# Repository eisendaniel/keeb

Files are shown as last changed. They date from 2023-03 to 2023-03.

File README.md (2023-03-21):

# un**ORTHO**dox

Devices

* UNO-XXX are main hosts, direct USB HID devices
* DOX-XXX are I2C expansion modules, connected via TRRS to the I2C bus and 5V power rails

## **UNO-W14** : 14x5 ortholinear keyboard

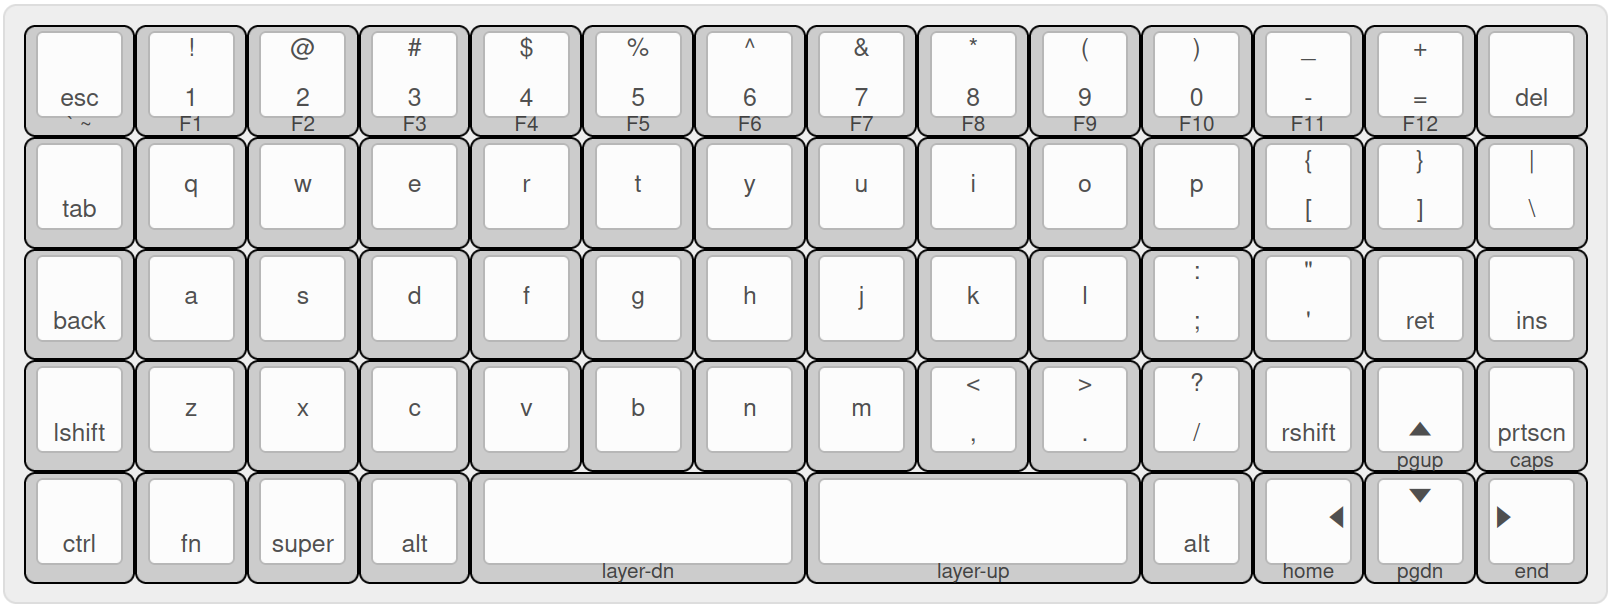
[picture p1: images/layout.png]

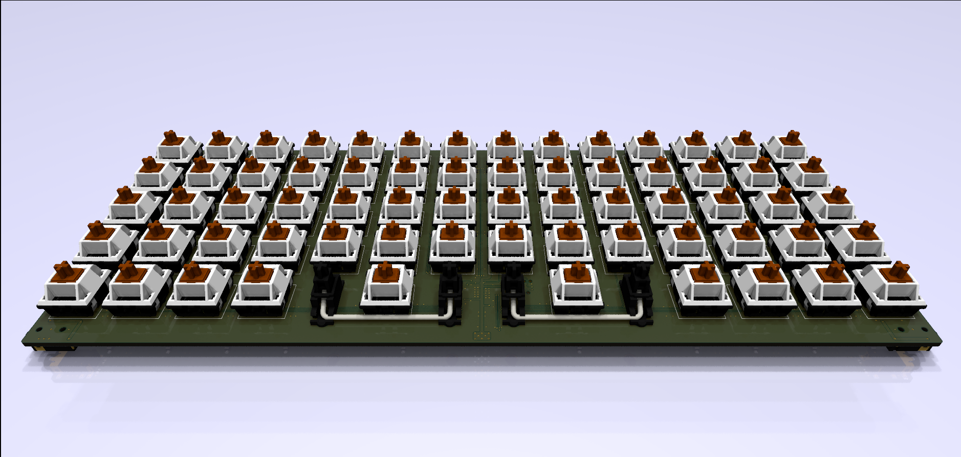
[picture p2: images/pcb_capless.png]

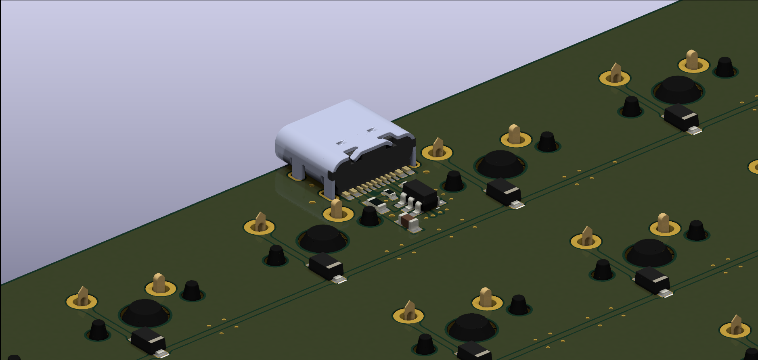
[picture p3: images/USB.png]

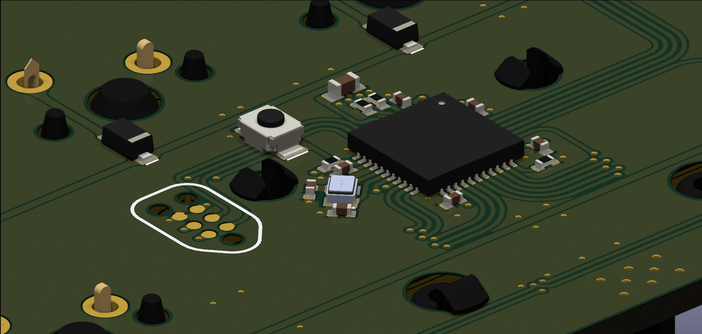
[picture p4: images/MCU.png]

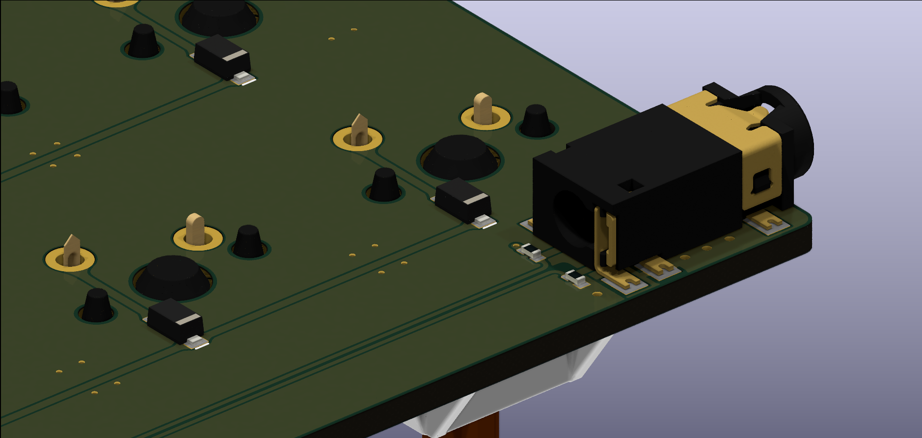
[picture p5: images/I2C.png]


## **DOX**-XXX : I2C expansion modules

[TODO] ... space for future development

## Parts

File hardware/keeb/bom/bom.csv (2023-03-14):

Reference | Value | Footprint | Datasheet | LCSC # | LCSC Link | Qty
C101, C107 | 1u | unORTHOdox:C_0603_1608Metric | https://datasheet.lcsc.com/lcsc/1810261812_Samsung-Electro-Mechanics-CL10A105KB8NNNC_C15849.pdf | C15849 | https://lcsc.com/product-detail/Multilayer-Ceramic-Capacitors-MLCC---SMD-SMT_Samsung-Electro-Mechanics-Samsung-Electro-Mechanics-CL10A105KB8NNNC_C15849.html | 2
C102-C106 | 100n | unORTHOdox:C_0402_1005Metric | https://datasheet.lcsc.com/lcsc/1810191219_Samsung-Electro-Mechanics-CL05B104KO5NNNC_C1525.pdf | C1525 | https://www.lcsc.com/product-detail/Multilayer-Ceramic-Capacitors-MLCC---SMD-SMT_Samsung-Electro-Mechanics-Samsung-Electro-Mechanics-CL05B104KO5NNNC_C1525.html | 5
C108, C109 | 12p | unORTHOdox:C_0402_1005Metric | https://datasheet.lcsc.com/lcsc/1811141710_FH--Guangdong-Fenghua-Advanced-Tech-0402CG120J500NT_C1547.pdf | C1547 | https://www.lcsc.com/product-detail/Multilayer-Ceramic-Capacitors-MLCC---SMD-SMT_FH-Guangdong-Fenghua-Advanced-Tech-FH-Guangdong-Fenghua-Advanced-Tech-0402CG1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 | 2
D101-D166 | D | unORTHOdox:D_SOD-123F | https://datasheet.lcsc.com/lcsc/1809301215_MDD-Microdiode-Electronics--SM4007PL_C64898.pdf | C64898 | https://www.lcsc.com/product-detail/Diodes---General-Purpose_MDD（Microdiode-Electronics）-MDD（Microdiode-Electronics）-SM4007PL_C64898.html | 66
F101 | 500mA | unORTHOdox:Fuse_0603_1608Metric | https://datasheet.lcsc.com/lcsc/1912111437_Jinrui-Electronic-Materials-Co--JK-NSMD050-13-2V_C369159.pdf | C369159 | https://www.lcsc.com/product-detail/Resettable-Fuses_Jinrui-Electronic-Materials-Co.-Jinrui-Electronic-Materials-Co.-JK-NSMD050-13.2V_C369159.html | 1
H101, H102 | MountingHole | PCM_Mounting_Keyboard_Stabilizer:Stabilizer_Cherry_MX_3.00u | ~ |  |  | 2
I2C_101, I2C_102 | AudioJack4 | unORTHOdox:Jack_3.5mm_TIC54-00177_Horizontal | https://datasheet.lcsc.com/lcsc/2110151730_XKB-Connectivity-PJ-342B-TX-SMT_C388632.pdf | C388632 | https://www.lcsc.com/product-detail/Audio-Connectors_XKB-Connectivity-XKB-Connectivity-PJ-342B-TX-SMT_C388632.html | 2
J101 | AVR-ISP-6 | Stamp_Attach:Stamp-Attach_SA2030-IDC-NL_2x03_P1.27mm_Vertical | ~ |  |  | 1
J102 | USB_C_Receptacle_USB2.0 | unORTHOdox:USB_C_Receptacle_HRO_TYPE-C-31-M-12 | https://datasheet.lcsc.com/lcsc/2205251630_Korean-Hroparts-Elec-TYPE-C-31-M-12_C165948.pdf | C165948 | https://www.lcsc.com/product-detail/USB-Connectors_Korean-Hroparts-Elec-Korean-Hroparts-Elec-TYPE-C-31-M-12_C165948.html | 1
R101, R102 | 5K1 | unORTHOdox:R_0402_1005Metric | https://datasheet.lcsc.com/lcsc/2206010045_UNI-ROYAL-Uniroyal-Elec-0402WGF5101TCE_C25905.pdf | C25905 | https://www.lcsc.com/product-detail/Chip-Resistor---Surface-Mount_UNI-ROYALUniroyal-Elec-UNI-ROYALUniroyal-Elec-0402WGF5101TCE_C25905.html | 2
R103-R106 | 4K7 | unORTHOdox:R_0402_1005Metric | https://datasheet.lcsc.com/lcsc/2206010045_UNI-ROYAL-Uniroyal-Elec-0402WGF4701TCE_C25900.pdf | C25900 | https://www.lcsc.com/product-detail/Chip-Resistor---Surface-Mount_UNI-ROYALUniroyal-Elec-UNI-ROYALUniroyal-Elec-0402WGF4701TCE_C25900.html | 4
R107, R108 | 22R | unORTHOdox:R_0402_1005Metric | https://datasheet.lcsc.com/lcsc/2205311900_UNI-ROYAL-Uniroyal-Elec-0402WGF220JTCE_C25092.pdf | C25092 | https://lcsc.com/product-detail/Chip-Resistor---Surface-Mount_UNI-ROYALUniroyal-Elec-UNI-ROYALUniroyal-Elec-0402WGF220JTCE_C25092.html | 2
R109, R110 | 10k | unORTHOdox:R_0402_1005Metric | https://datasheet.lcsc.com/lcsc/2206010100_UNI-ROYAL-Uniroyal-Elec-0402WGF1002TCE_C25744.pdf | C25744 | https://www.lcsc.com/product-detail/Chip-Resistor---Surface-Mount_UNI-ROYALUniroyal-Elec-UNI-ROYALUniroyal-Elec-0402WGF1002TCE_C25744.html | 2
SW101-SW166 | SW_Push | PCM_Switch_Keyboard_Cherry_MX:SW_Cherry_MX_PCB_1.00u | ~ |  |  | 66
SW167 | SW_Push | unORTHOdox:SW_SPST_B3U-1000P | https://datasheet.lcsc.com/lcsc/1810010153_Omron-Electronics-B3U-1000P_C231329.pdf | C231329 | https://www.lcsc.com/product-detail/Tactile-Switches_Omron-Electronics-Omron-Electronics-B3U-1000P_C231329.html | 1
U101 | TPD2S017 | unORTHOdox:SOT-23-6 | http://www.ti.com/lit/ds/symlink/tpd2s017.pdf | C880115 | https://www.lcsc.com/product-detail/ESD-Protection-Devices_Texas-Instruments-Texas-Instruments-TPD2S017DBVR_C880115.html | 1
U102 | ATmega32U4-MU | unORTHOdox:QFN-44-1EP_7x7mm_P0.5mm_EP5.2x5.2mm | http://ww1.microchip.com/downloads/en/DeviceDoc/Atmel-7766-8-bit-AVR-ATmega16U4-32U4_Datasheet.pdf | C112161 | https://www.lcsc.com/product-detail/Microcontroller-Units-MCUs-MPUs-SOCs_Microchip-Tech-Microchip-Tech-ATMEGA32U4-MU_C112161.html | 1
Y101 | 16Mhz | unORTHOdox:Crystal_SMD_2016-4Pin_2.0x1.6mm | https://datasheet.lcsc.com/lcsc/1912111437_YL-Failong-Crystal-9S16000020_C431146.pdf | C431146 | https://www.lcsc.com/product-detail/Crystals_YLFailong-Crystal-YLFailong-Crystal-9S16000020_C431146.html | 1

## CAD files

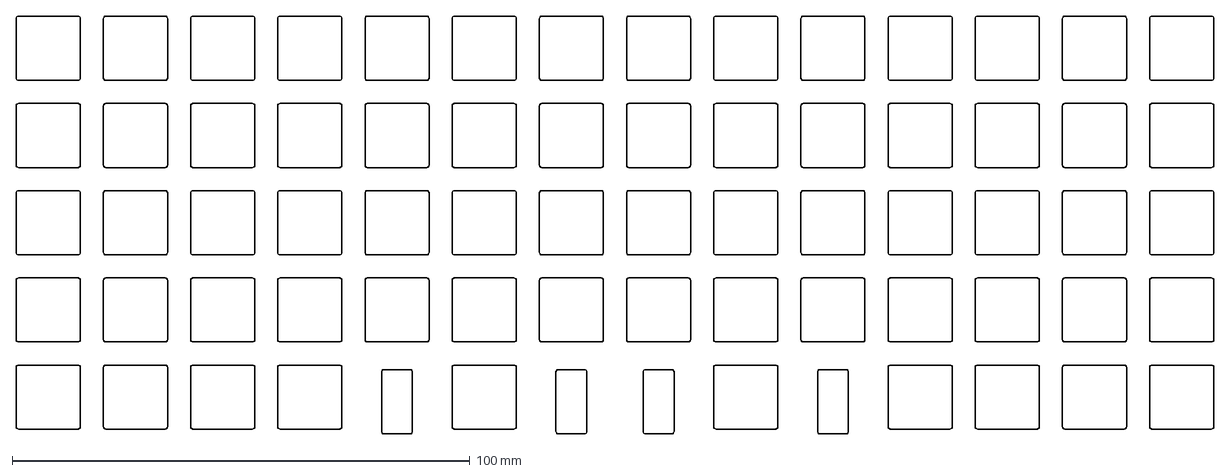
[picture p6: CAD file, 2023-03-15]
design/kbplate.dxf
261.7 x 91.2 mm

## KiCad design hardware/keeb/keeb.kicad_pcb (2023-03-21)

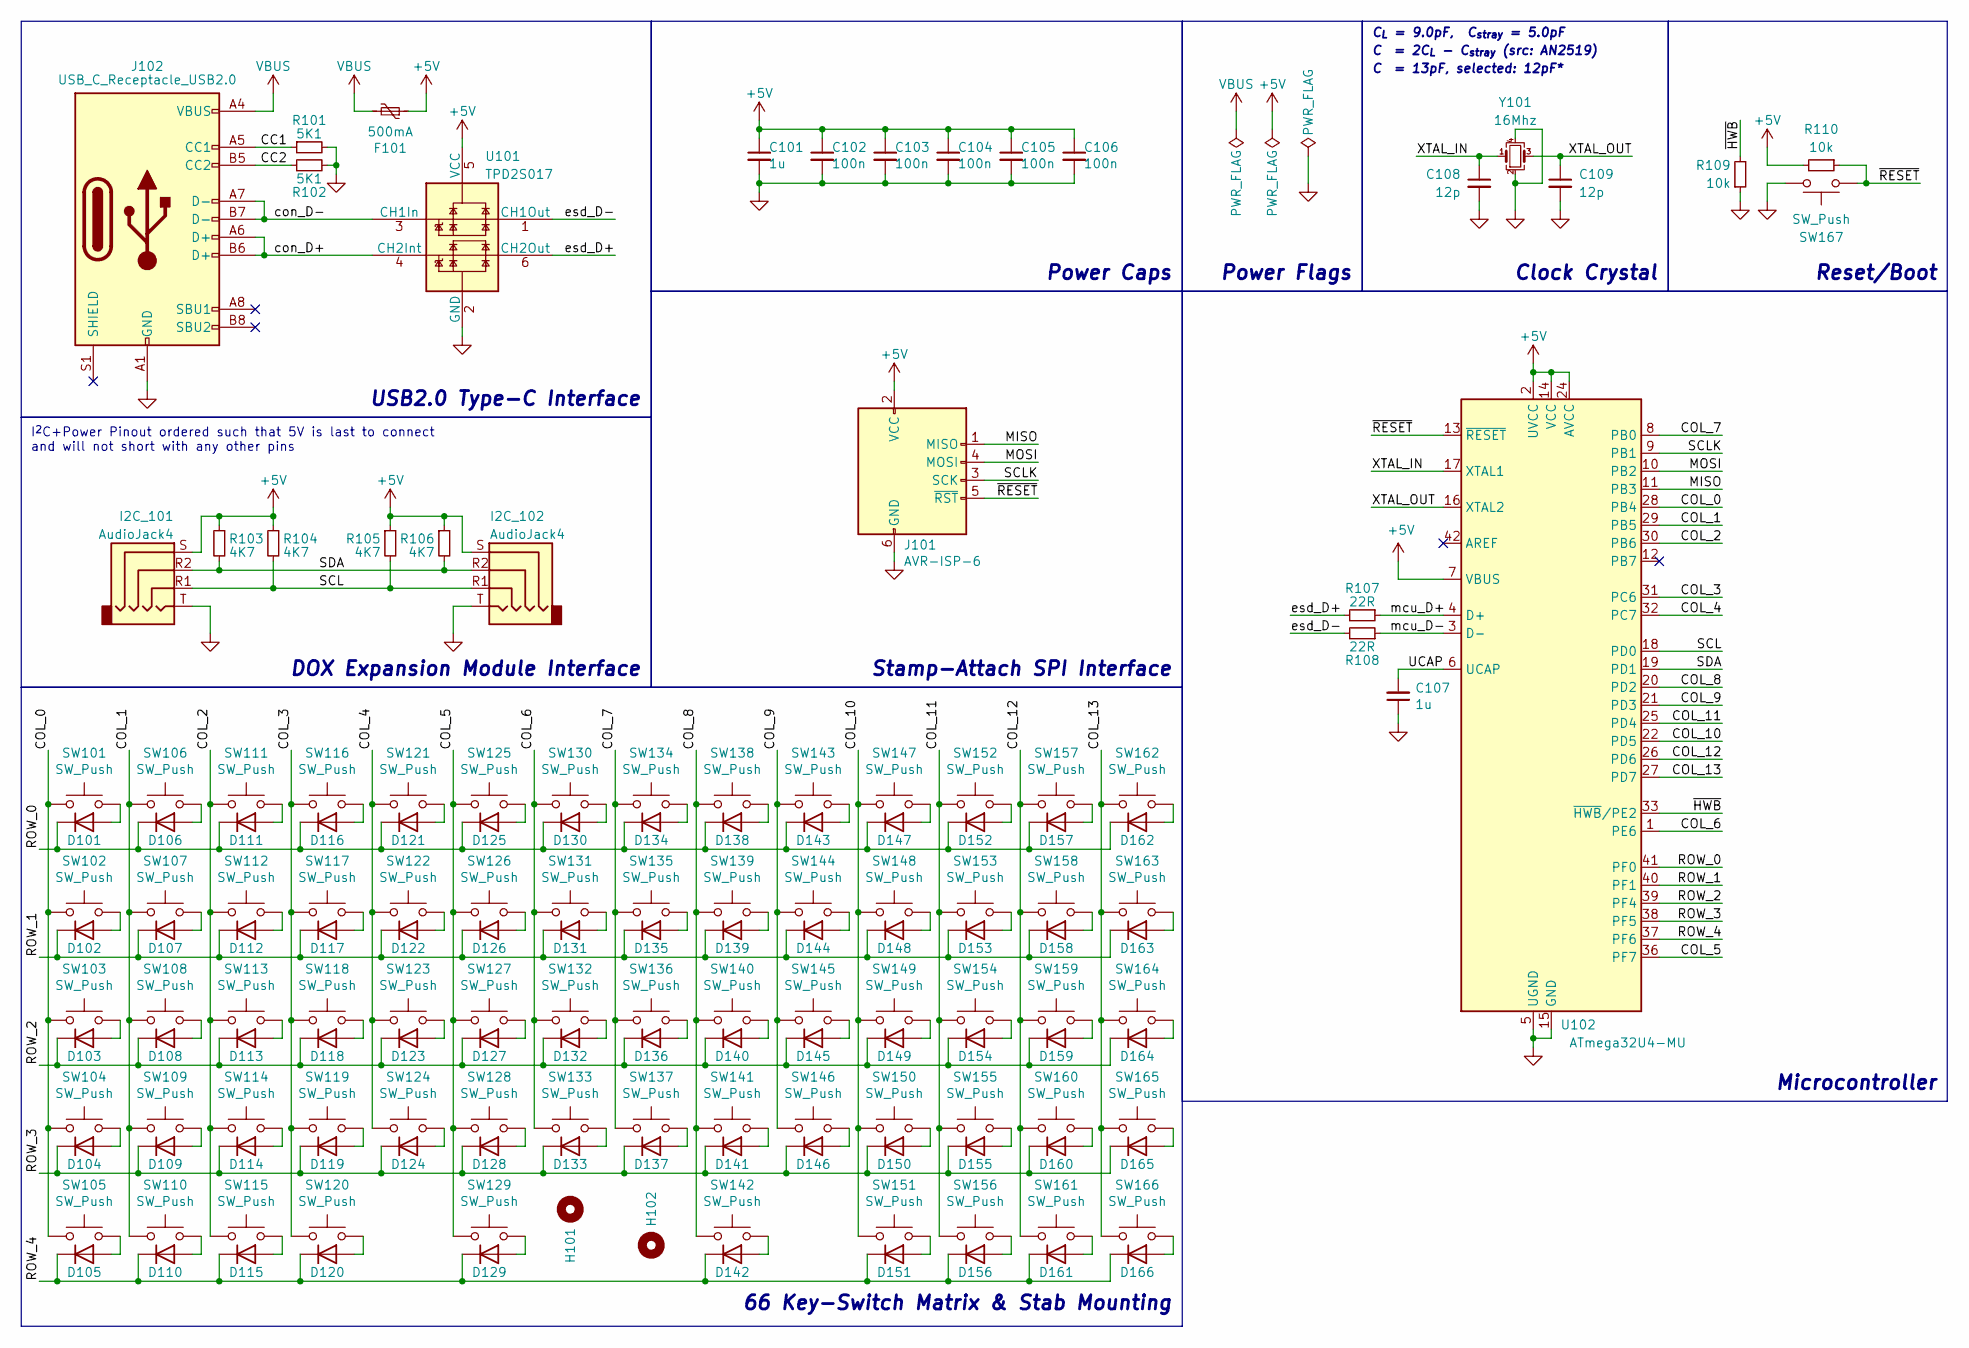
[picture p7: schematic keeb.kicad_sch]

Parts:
C101, C107: 1u; C_0603_1608Metric; LCSC # C15849
C102, C103, C104, C105, C106: 100n; C_0402_1005Metric; LCSC # C1525
C108, C109: 12p; C_0402_1005Metric; LCSC # C1547
D101, D102, D103, D104, D105, D106, D107, D108, D109, D110, D111, D112, D113, D114, D115, D116, D117, D118, D119, D120, D121, D122, D123, D124, D125, D126, D127, D128, D129, D130, D131, D132, D133, D134, D135, D136, D137, D138, D139, D140, D141, D142, D143, D144, D145, D146, D147, D148, D149, D150, D151, D152, D153, D154, D155, D156, D157, D158, D159, D160, D161, D162, D163, D164, D165, D166: D; D_SOD-123F; LCSC # C64898
F101: 500mA; Fuse_0603_1608Metric; LCSC # C369159
H101, H102: MountingHole; Stabilizer_Cherry_MX_3.00u
I2C_101, I2C_102: AudioJack4; Jack_3.5mm_TIC54-00177_Horizontal; LCSC # C388632
J101: AVR-ISP-6; Stamp-Attach_SA2030-IDC-NL_2x03_P1.27mm_Vertical
J102: USB_C_Receptacle_USB2.0; USB_C_Receptacle_HRO_TYPE-C-31-M-12; LCSC # C165948
R101, R102: 5K1; R_0402_1005Metric; LCSC # C25905
R103, R104, R105, R106: 4K7; R_0402_1005Metric; LCSC # C25900
R107, R108: 22R; R_0402_1005Metric; LCSC # C25092
R109, R110: 10k; R_0402_1005Metric; LCSC # C25744
SW101, SW102, SW103, SW104, SW105, SW106, SW107, SW108, SW109, SW110, SW111, SW112, SW113, SW114, SW115, SW116, SW117, SW118, SW119, SW120, SW121, SW122, SW123, SW124, SW125, SW126, SW127, SW128, SW129, SW130, SW131, SW132, SW133, SW134, SW135, SW136, SW137, SW138, SW139, SW140, SW141, SW142, SW143, SW144, SW145, SW146, SW147, SW148, SW149, SW150, SW151, SW152, SW153, SW154, SW155, SW156, SW157, SW158, SW159, SW160, SW161, SW162, SW163, SW164, SW165, SW166: SW_Push; SW_Cherry_MX_PCB_1.00u
SW167: SW_Push; SW_SPST_B3U-1000P; LCSC # C231329
U101: TPD2S017; SOT-23-6; LCSC # C880115
U102: ATmega32U4-MU; QFN-44-1EP_7x7mm_P0.5mm_EP5.2x5.2mm; LCSC # C112161
Y101: 16Mhz; Crystal_SMD_2016-4Pin_2.0x1.6mm; LCSC # C431146

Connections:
+5V: C101.1, C102.1, C103.1, C104.1, C105.1, C106.1, F101.1, I2C_101.S, I2C_102.S, J101.2 (VCC), R103.1, R104.1, R105.1, R106.1, R110.2, U101.5 (VCC), U102.2 (UVCC), U102.7 (VBUS), U102.14 (VCC), U102.24 (AVCC), U102.34 (VCC), U102.44 (AVCC)
/CC1: J102.A5 (CC1), R101.1
/CC2: J102.B5 (CC2), R102.1
/COL_0: SW101.1, SW102.1, SW103.1, SW104.1, SW105.1, U102.28 (PB4)
/COL_1: SW106.1, SW107.1, SW108.1, SW109.1, SW110.1, U102.29 (PB5)
/COL_2: SW111.1, SW112.1, SW113.1, SW114.1, SW115.1, U102.30 (PB6)
/COL_3: SW116.1, SW117.1, SW118.1, SW119.1, SW120.1, U102.31 (PC6)
/COL_4: SW121.1, SW122.1, SW123.1, SW124.1, U102.32 (PC7)
/COL_5: SW125.1, SW126.1, SW127.1, SW128.1, SW129.1, U102.36 (PF7)
/COL_6: SW130.1, SW131.1, SW132.1, SW133.1, U102.1 (PE6)
/COL_7: SW134.1, SW135.1, SW136.1, SW137.1, U102.8 (PB0)
/COL_8: SW138.1, SW139.1, SW140.1, SW141.1, SW142.1, U102.20 (PD2)
/COL_9: SW143.1, SW144.1, SW145.1, SW146.1, U102.21 (PD3)
/COL_10: SW147.1, SW148.1, SW149.1, SW150.1, SW151.1, U102.22 (PD5)
/COL_11: SW152.1, SW153.1, SW154.1, SW155.1, SW156.1, U102.25 (PD4)
/COL_12: SW157.1, SW158.1, SW159.1, SW160.1, SW161.1, U102.26 (PD6)
/COL_13: SW162.1, SW163.1, SW164.1, SW165.1, SW166.1, U102.27 (PD7)
/MISO: J101.1 (MISO), U102.11 (PB3)
/MOSI: J101.4 (MOSI), U102.10 (PB2)
/ROW_0: D101.1 (K), D106.1 (K), D111.1 (K), D116.1 (K), D121.1 (K), D125.1 (K), D130.1 (K), D134.1 (K), D138.1 (K), D143.1 (K), D147.1 (K), D152.1 (K), D157.1 (K), D162.1 (K), U102.41 (PF0)
/ROW_1: D102.1 (K), D107.1 (K), D112.1 (K), D117.1 (K), D122.1 (K), D126.1 (K), D131.1 (K), D135.1 (K), D139.1 (K), D144.1 (K), D148.1 (K), D153.1 (K), D158.1 (K), D163.1 (K), U102.40 (PF1)
/ROW_2: D103.1 (K), D108.1 (K), D113.1 (K), D118.1 (K), D123.1 (K), D127.1 (K), D132.1 (K), D136.1 (K), D140.1 (K), D145.1 (K), D149.1 (K), D154.1 (K), D159.1 (K), D164.1 (K), U102.39 (PF4)
/ROW_3: D104.1 (K), D109.1 (K), D114.1 (K), D119.1 (K), D124.1 (K), D128.1 (K), D133.1 (K), D137.1 (K), D141.1 (K), D146.1 (K), D150.1 (K), D155.1 (K), D160.1 (K), D165.1 (K), U102.38 (PF5)
/ROW_4: D105.1 (K), D110.1 (K), D115.1 (K), D120.1 (K), D129.1 (K), D142.1 (K), D151.1 (K), D156.1 (K), D161.1 (K), D166.1 (K), U102.37 (PF6)
/SCL: I2C_101.R1, I2C_102.R1, R104.2, R105.2, U102.18 (PD0)
/SCLK: J101.3 (SCK), U102.9 (PB1)
/SDA: I2C_101.R2, I2C_102.R2, R103.2, R106.2, U102.19 (PD1)
/UCAP: C107.2, U102.6 (UCAP)
/XTAL_IN: C108.1, U102.17 (XTAL1), Y101.1
/XTAL_OUT: C109.1, U102.16 (XTAL2), Y101.3
/con_D+: J102.A6 (D+), J102.B6 (D+), U101.4 (CH2Int)
/con_D-: J102.A7 (D-), J102.B7 (D-), U101.3 (CH1In)
/esd_D+: R107.2, U101.6 (CH2Out)
/esd_D-: R108.2, U101.1 (CH1Out)
/mcu_D+: R107.1, U102.4 (D+)
/mcu_D-: R108.1, U102.3 (D-)
/~HWB: R109.2, U102.33 (~HWB/PE2)
/~RESET: J101.5 (~RST), R110.1, SW167.1, U102.13 (~RESET)
GND: C101.2, C102.2, C103.2, C104.2, C105.2, C106.2, C107.1, C108.2, C109.2, I2C_101.T, I2C_102.T, J101.6 (GND), J102.A1 (GND), J102.A12 (GND), J102.B1 (GND), J102.B12 (GND), R101.2, R102.2, R109.1, SW167.2, U101.2 (GND), U102.5 (UGND), U102.15 (GND), U102.23 (GND), U102.35 (GND), U102.43 (GND), U102.45 (GND), Y101.2, Y101.4
unnamed: D101.2 (A), SW101.2
unnamed: D102.2 (A), SW102.2
unnamed: D103.2 (A), SW103.2
unnamed: D104.2 (A), SW104.2
unnamed: D105.2 (A), SW105.2
unnamed: D106.2 (A), SW106.2
unnamed: D107.2 (A), SW107.2
unnamed: D108.2 (A), SW108.2
unnamed: D109.2 (A), SW109.2
unnamed: D110.2 (A), SW110.2
unnamed: D111.2 (A), SW111.2
unnamed: D112.2 (A), SW112.2
unnamed: D113.2 (A), SW113.2
unnamed: D114.2 (A), SW114.2
unnamed: D115.2 (A), SW115.2
unnamed: D116.2 (A), SW116.2
unnamed: D117.2 (A), SW117.2
unnamed: D118.2 (A), SW118.2
unnamed: D119.2 (A), SW119.2
unnamed: D120.2 (A), SW120.2
unnamed: D121.2 (A), SW121.2
unnamed: D122.2 (A), SW122.2
unnamed: D123.2 (A), SW123.2
unnamed: D124.2 (A), SW124.2
unnamed: D125.2 (A), SW125.2
unnamed: D126.2 (A), SW126.2
unnamed: D127.2 (A), SW127.2
unnamed: D128.2 (A), SW128.2
unnamed: D129.2 (A), SW129.2
unnamed: D130.2 (A), SW130.2
unnamed: D131.2 (A), SW131.2
unnamed: D132.2 (A), SW132.2
unnamed: D133.2 (A), SW133.2
unnamed: D134.2 (A), SW134.2
unnamed: D135.2 (A), SW135.2
unnamed: D136.2 (A), SW136.2
unnamed: D137.2 (A), SW137.2
unnamed: D138.2 (A), SW138.2
unnamed: D139.2 (A), SW139.2
unnamed: D140.2 (A), SW140.2
unnamed: D141.2 (A), SW141.2
unnamed: D142.2 (A), SW142.2
unnamed: D143.2 (A), SW143.2
unnamed: D144.2 (A), SW144.2
unnamed: D145.2 (A), SW145.2
unnamed: D146.2 (A), SW146.2
unnamed: D147.2 (A), SW147.2
unnamed: D148.2 (A), SW148.2
unnamed: D149.2 (A), SW149.2
unnamed: D150.2 (A), SW150.2
unnamed: D151.2 (A), SW151.2
unnamed: D152.2 (A), SW152.2
unnamed: D153.2 (A), SW153.2
unnamed: D154.2 (A), SW154.2
unnamed: D155.2 (A), SW155.2
unnamed: D156.2 (A), SW156.2
unnamed: D157.2 (A), SW157.2
unnamed: D158.2 (A), SW158.2
unnamed: D159.2 (A), SW159.2
unnamed: D160.2 (A), SW160.2
unnamed: D161.2 (A), SW161.2
unnamed: D162.2 (A), SW162.2
unnamed: D163.2 (A), SW163.2
unnamed: D164.2 (A), SW164.2
unnamed: D165.2 (A), SW165.2
unnamed: D166.2 (A), SW166.2
VBUS: F101.2, J102.A4 (VBUS), J102.A9 (VBUS), J102.B4 (VBUS), J102.B9 (VBUS)

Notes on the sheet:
Reset/Boot
DOX Expansion Module Interface
Power Caps
Power Flags
Clock Crystal
C_{L} = 9.0pF, C_{stray} = 5.0pF
C_{ } = 2C_{L} - C_{stray} (src: AN2519)
I^{2}C+Power Pinout ordered such that 5V is last to connect and will not short with any other pins
C_{ } = 13pF, selected: 12pF*
USB2.0 Type-C Interface
Microcontroller
66 Key-Switch Matrix & Stab Mounting
Stamp-Attach SPI Interface

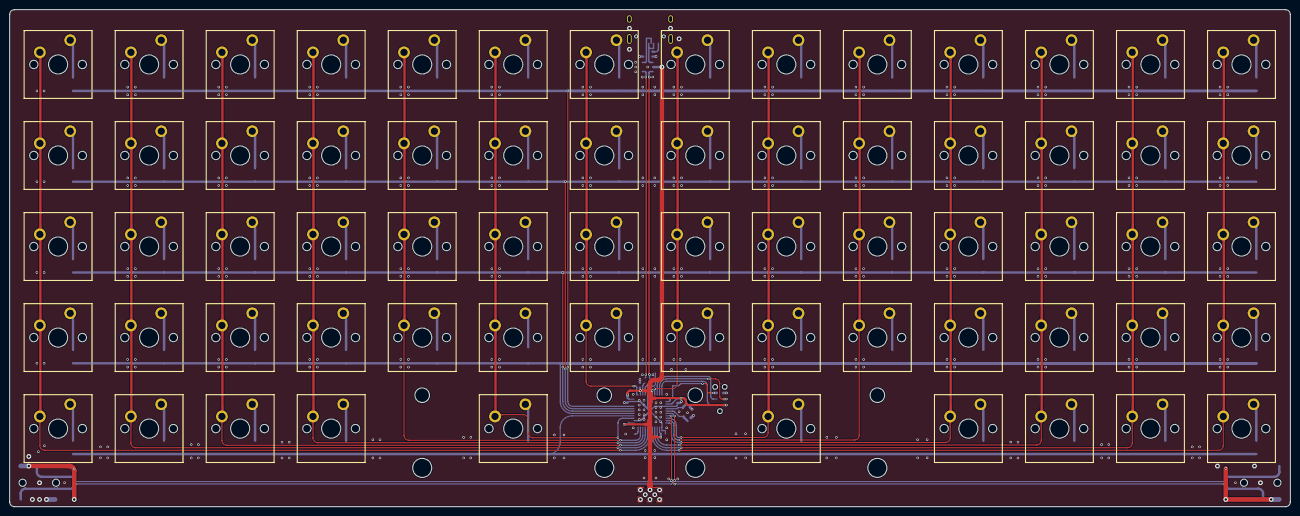
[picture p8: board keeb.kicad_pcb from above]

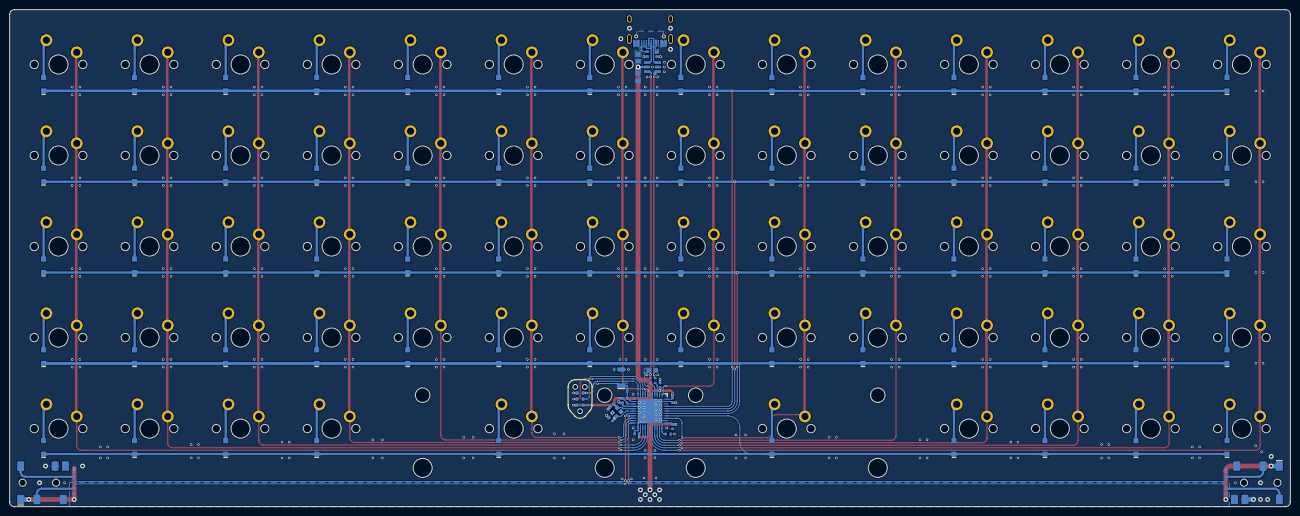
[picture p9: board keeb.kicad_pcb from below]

Board: 2 copper layers, 268.0 x 104.0 mm, 162 parts (94 on the bottom side), 106 nets.

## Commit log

2021-11-24 schem compl, layout sw, mat routing
    [keeb.kicad_pcb, keeb.sch]
2021-11-25 col, USB, and gnd layout
    [keeb.kicad_pcb, keeb.sch]
2021-11-25 first pass layout complete
    [keeb.kicad_pcb, keeb.sch]
2021-11-25 lp rst sw
    [keeb.kicad_pcb, keeb.sch]
2021-11-25 added plate subdir
    [keeb.kicad_pcb, keeb.sch, plate.kicad_pcb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]
2021-11-25 plate brd size
    [plate.kicad_pcb]
2021-11-26 reset route cleanup
    [keeb.kicad_pcb]
2021-11-26 usb width delta trans
    [keeb.kicad_pcb]
2021-11-26 plate edge cuts
    [keeb.kicad_pcb, plate.dxf, plate.kicad_pcb]
2021-11-26 plate fill
    [plate.kicad_pcb]
2021-11-26 USB power cleanup
    [keeb.kicad_pcb]
2021-11-26 del cad
2021-11-26 unpop ISP
    [keeb.kicad_pcb]
2021-11-26 uniform diode routes
    [keeb.kicad_pcb]
2021-11-27 CLOSED PLATE
    [keeb.kicad_pcb, plate.dxf, plate.kicad_pcb]
2021-11-28 i2c fin
    [keeb.kicad_pcb, keeb.sch, plate.kicad_pcb]
2021-11-28 updated bulk decoupling and usb-c routing
    [keeb.kicad_pcb, keeb.sch]
2021-11-28 USB power pour alignment
    [keeb.kicad_pcb]
2021-11-28 update I2C routing
    [keeb.kicad_pcb]
2021-11-28 DSA keycap mods
    [keeb.kicad_pcb]
2021-11-29 fixed f mask fp
    [keeb.kicad_pcb, keeb.sch]
2021-11-29 silk cleanu
    [keeb.kicad_pcb, keeb.sch]
2021-11-29 copper pour filling, mounting m2 holes pass 1
    [keeb.kicad_pcb, plate.kicad_pcb]
2021-12-15 fix sw mod and left over routing cleaning
    [keeb.kicad_pcb]
2021-12-16 logo begin
    [keeb.kicad_pcb]
2022-01-11 kicad 6 upgrade
    [keeb.kicad_pcb, keeb.kicad_sch, keeb.sch]
2022-01-16 clean trace
    [keeb.kicad_pcb, keeb.kicad_sch]
2022-01-18 qfn layout complete
    [keeb.kicad_pcb, keeb.kicad_sch]
2022-01-26 trace widths unified
    [keeb.kicad_pcb, keeb.kicad_sch]
2022-01-26 5V clean
    [keeb.kicad_pcb]
2022-01-26 complete via stitch
    [keeb.kicad_pcb]
2022-01-26 5V curved
    [keeb.kicad_pcb]
2022-01-26 origin and step
    [keeb.kicad_pcb]
2022-01-26 plate resize
    [plate.kicad_pcb, plate.step]
2023-03-07 RESTART: Version2
    [keeb.kicad_pcb, keeb.kicad_sch, plate.dxf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]
2023-03-07 footprints/general libs redone
    [keeb.kicad_sch]
2023-03-08 matrix and row/colrouting
    [keeb.kicad_pcb, keeb.kicad_sch]
2023-03-09 usb/matrix/mcu routing
    [keeb.kicad_pcb, keeb.kicad_sch]
2023-03-09 layout cont, fp mcu updated
    [keeb.kicad_pcb, keeb.kicad_sch]
2023-03-10 footprints, part selection, cleanupo
    [keeb.kicad_pcb, keeb.kicad_sch]
2023-03-10 row and col via and trace spacing and fillets
    [keeb.kicad_pcb, keeb.kicad_sch]
2023-03-10 First Routing Pass Complete
    [keeb.kicad_pcb]
2023-03-11 LCSC part selected
    [keeb.kicad_pcb, keeb.kicad_sch]
2023-03-11 route cleanup
    [keeb.kicad_pcb]
2023-03-13 all FP cleaned up and updated
    [keeb.kicad_pcb, keeb.kicad_sch]
2023-03-13 image exports and crystal model
    [keeb.kicad_pcb]
2023-03-14 HTML Bom, osc load cap redo and schem org
    [keeb.kicad_pcb, keeb.kicad_sch]
2023-03-14 repo reorg and PCB complete (pre fabhouse specifics)
    [keeb.kicad_pcb, keeb.kicad_sch, unORTHOdox W14.kicad_pcb]
2023-03-14 final parts and LCSC bom
    [LCSC_Bom_Exported_2023-03-15.csv, bom.csv, keeb.kicad_pcb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]
2023-03-15 fp pin1 cleanup and general route polish (focus on i2c)
    [keeb.kicad_pcb]
2023-03-15 plate start
    [kbplate.dxf, keeb.kicad_pcb]
2023-03-16 updated layout and extended i2c jacks
    [keeb.kicad_pcb]
2023-03-17 svg exports for silkscreening
    [keeb.kicad_pcb]
2023-03-21 schem info text, and README updated
    [keeb.kicad_pcb, keeb.kicad_sch]
